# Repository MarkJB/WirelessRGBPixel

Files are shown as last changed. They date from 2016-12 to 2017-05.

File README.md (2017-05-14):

Copyright 2016 Mark Benson.

License: CC-NC-BY 4.0

No warranty implied or given. Use at your own risk.

Early testing code/electronics for proof of concept.

Wireless RGB Pixel is just that, a wireless (NRF24L01+) RGB led (WS2812b) controlled by an Atmel ATTiny85. One or more 'pixels' can be controlled by an Arduino with another NRF24L01+ module.

It is hoped that many of these 'pixels' can be manufactured and installed somewhere and controlled to create an interesting light show.

As of Dec 2016 PCB is at v1.2.

This version uses the original circuit design. No pin mux or serial debug is available.

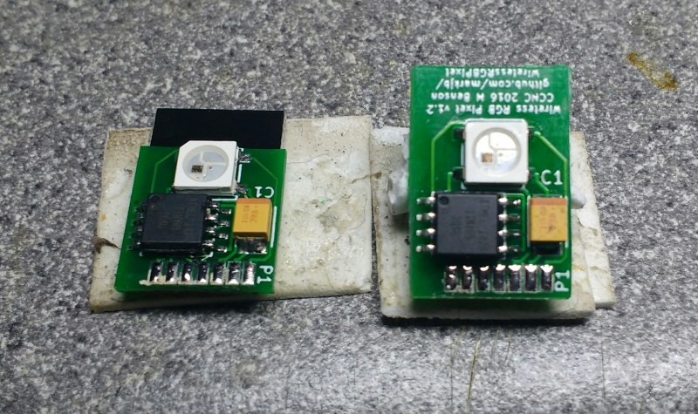
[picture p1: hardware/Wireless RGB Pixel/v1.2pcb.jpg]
v1.2 PCB


More details on the Make Bournemouth Wiki and forum.

https://www.makebournemouth.com/wiki2/index.php/RGB_Wireless_Pixel

https://www.makebournemouth.com/?page_id=39

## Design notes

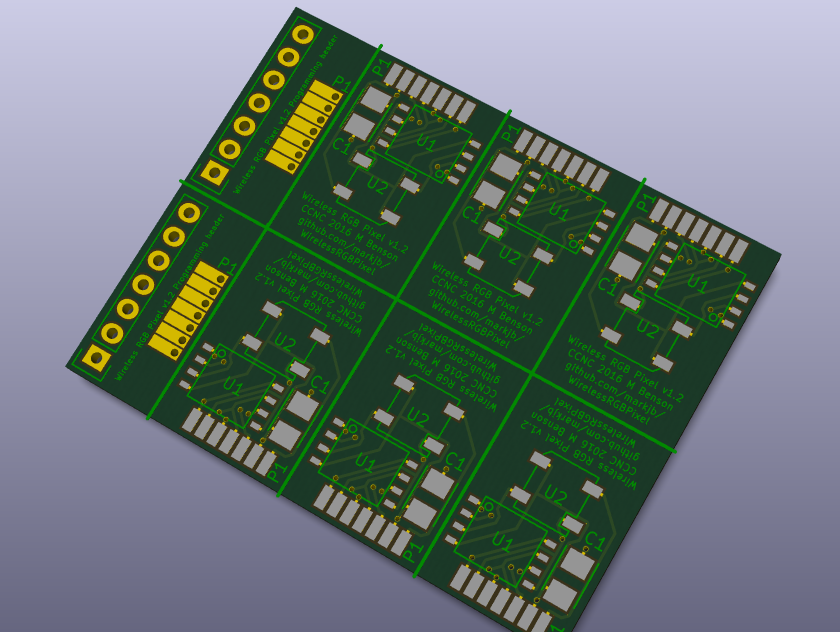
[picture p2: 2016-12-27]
hardware/Wireless RGB Pixel/tiny_pcb_1.2_panel3x2.png

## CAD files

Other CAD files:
hardware/Wireless RGB Pixel/pcb.stl

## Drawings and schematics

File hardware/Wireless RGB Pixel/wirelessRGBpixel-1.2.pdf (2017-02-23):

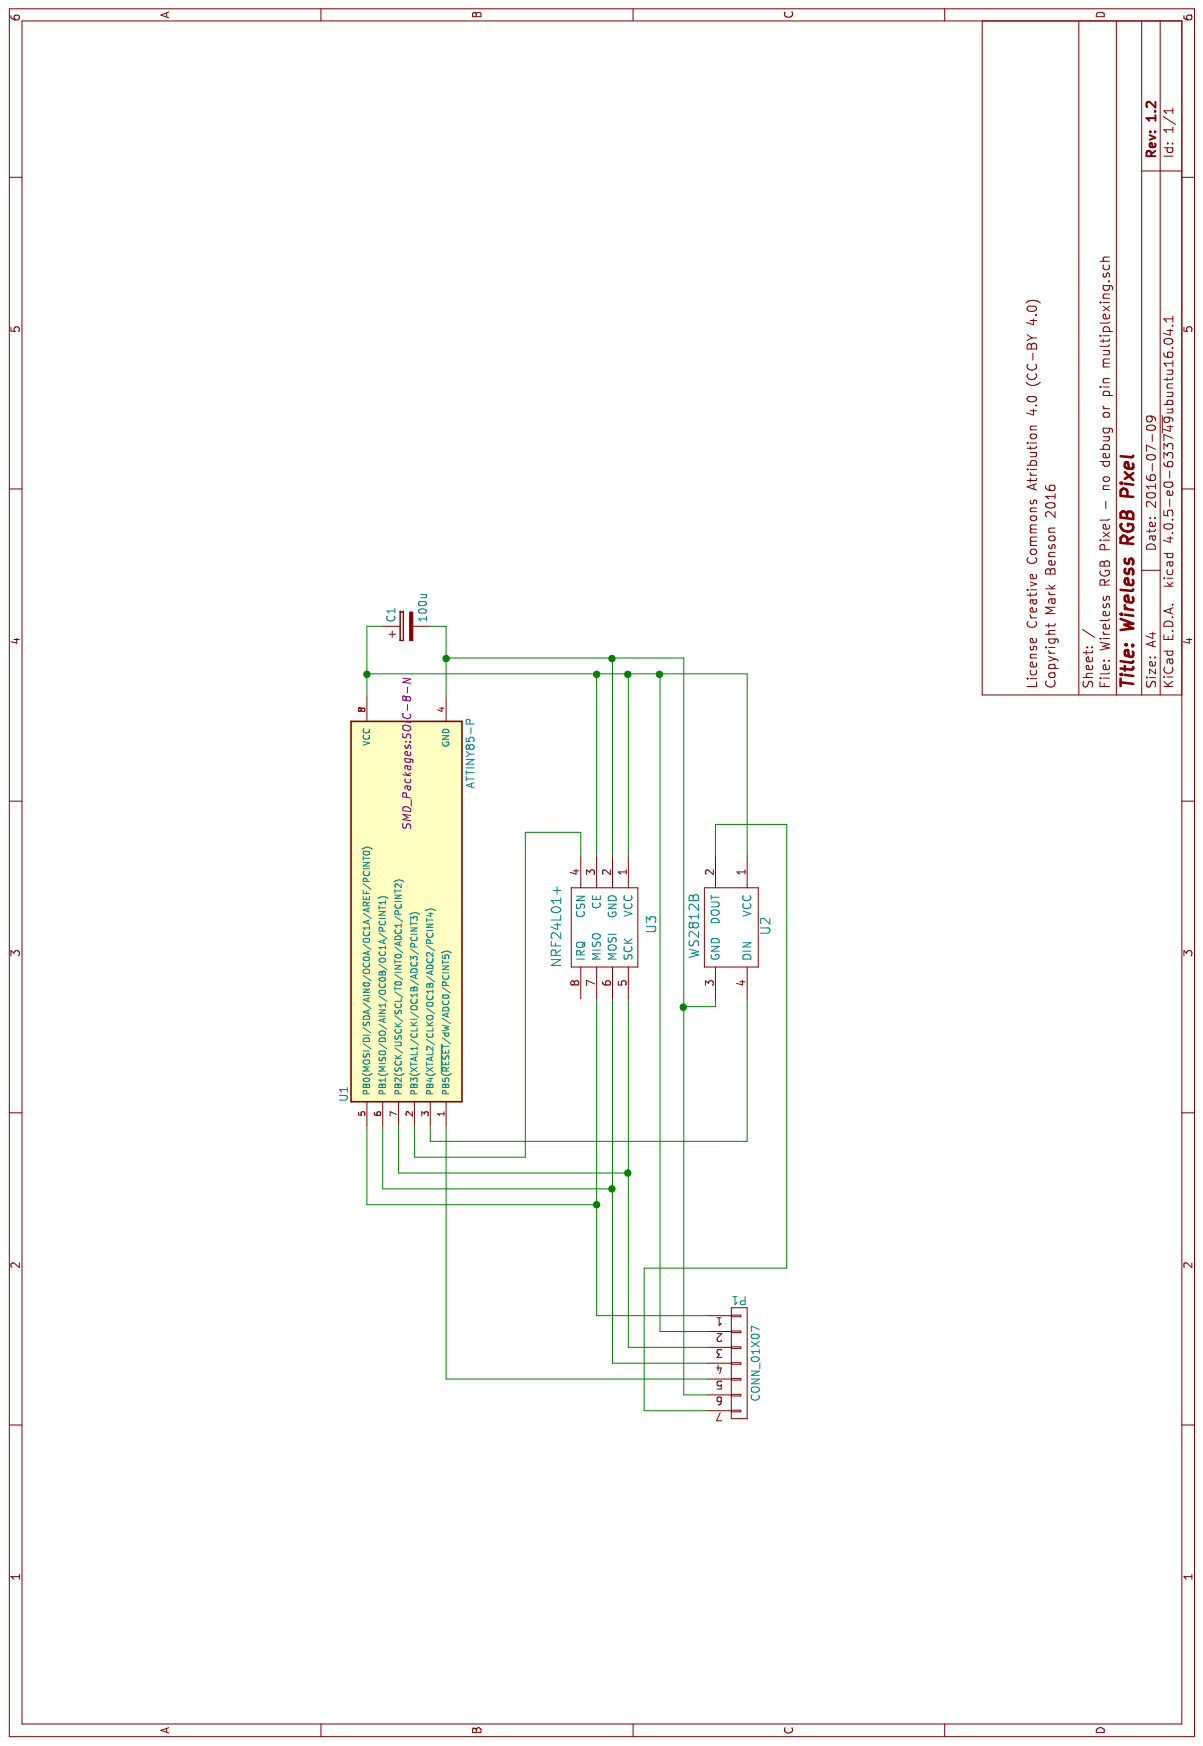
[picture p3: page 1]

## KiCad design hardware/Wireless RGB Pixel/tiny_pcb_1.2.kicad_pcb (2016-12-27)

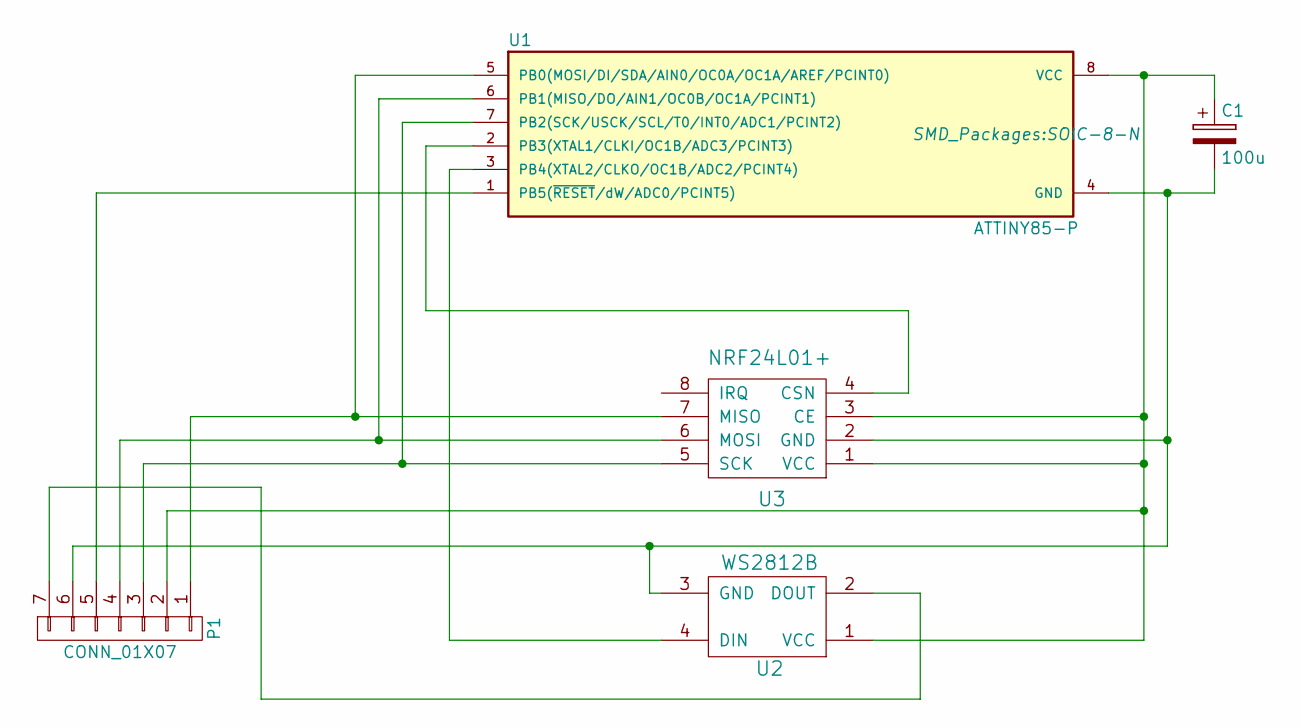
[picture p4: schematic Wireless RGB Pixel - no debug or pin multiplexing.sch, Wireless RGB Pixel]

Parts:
C1: 100u; TantalC_SizeB_EIA-3528_Reflow
P1: CONN_01X07; CONN7
U1: ATTINY85-P; SOIC-8-N
U2: WS2812B; WS2812B_SMT
U3: NRF24L01+; NRF24L01+_SMT

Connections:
unnamed: C1.1, P1.2, U1.8 (VCC), U2.1 (VCC), U3.1 (VCC), U3.3 (CE)
unnamed: C1.2, P1.6, U1.4 (GND), U2.3 (GND), U3.2 (GND)
unnamed: P1.1, U1.5 (PB0(MOSI/DI/SDA/AIN0/OC0A/OC1A/AREF/PCI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), U3.7 (MISO)
unnamed: P1.3, U1.7 (PB2(SCK/USCK/SCL/T0/INT0/ADC1/PCINT2)), U3.5 (SCK)
unnamed: P1.4, U1.6 (PB1(MISO/DO/AIN1/OC0B/OC1A/PCINT1)), U3.6 (MOSI)
unnamed: P1.5, U1.1 (PB5(~RESET~/dW/ADC0/PCINT5))
unnamed: P1.7, U2.2 (DOUT)
unnamed: U1.2 (PB3(XTAL1/CLKI/OC1B/ADC3/PCINT3)), U3.4 (CSN)
unnamed: U1.3 (PB4(XTAL2/CLKO/OC1B/ADC2/PCINT4)), U2.4 (DIN)

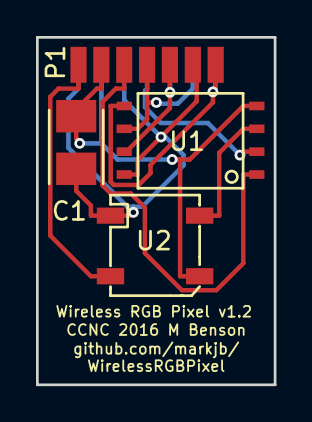
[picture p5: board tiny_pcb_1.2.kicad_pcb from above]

Board: 2 copper layers, 13.2 x 19.3 mm, 5 parts (1 on the bottom side), 9 nets.

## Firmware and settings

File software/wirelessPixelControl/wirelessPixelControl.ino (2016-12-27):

/*
* Getting Started example sketch for nRF24L01+ radios
* This is a very basic example of how to send data from one node to another
* Updated: Dec 2014 by TMRh20
*/

#include <SPI.h>
#include "RF24.h"

/****************** User Config ***************************/
/***      Set this radio as radio number 0 or 1         ***/
bool radioNumber = 0;

/* Hardware configuration: Set up nRF24L01 radio on SPI bus plus pins 7 & 8 */

// RF24 radio(CE,CSN)
// Arduino NANO NRF Adaptor board https://github.com/MarkJB/NRF24L01_Adaptors
RF24 radio(9,10);

/**********************************************************/

byte addresses[][6] = {"PIPE1","PIPE2"};

// Used to control whether this node is sending or receiving
bool role = 0;

int r,g,b;

void setup() {
  Serial.begin(115200);
  Serial.println("WirelessRGBPixel Control v1");
  Serial.println("Commands available:");
  Serial.println("Change colour: CR,G,B");
  Serial.println("Random colour: R");
  Serial.println("Turn off LEDs: O");
  Serial.println("Show this help info: H/?");
  Serial.println("Fade to black: Not implemented");
  Serial.println("Blend to colour: Not implemented");
  radio.begin();

  // Set the PA Level low to prevent power supply related issues since this is a
 // getting_started sketch, and the likelihood of close proximity of the devices. RF24_PA_MAX is default.
  radio.setPALevel(RF24_PA_MAX);
  
  // Open a writing and reading pipe on each radio, with opposite addresses
  if(radioNumber){
    radio.openWritingPipe(addresses[1]);
    radio.openReadingPipe(1,addresses[0]);
  }else{
    radio.openWritingPipe(addresses[0]);
    radio.openReadingPipe(1,addresses[1]);
  }
  
  // Start the radio listening for data
  radio.startListening();
}

void loop() 
{
  if ( Serial.available() )
  {
    char firstReceivedByte = toupper(Serial.read());
    
    switch(firstReceivedByte)
    {
      case 'C': //If the first char received is a 'C' that indicates a change colour CRGB command so get the rest of it and send it
      {
        Serial.println("Colour change command: Cn,n,n,a");
        byte sendRGBData[5] = {'C',0,0,0,0};  //Change colour command: C,R,G,B,a (defaults to off) where a is the pixel address 0-255 (0 is default and address all pixels)
        if (Serial.available() >= 2) 
        {
          for (int i=1; i<5; i++) 
          {
            sendRGBData[i] = Serial.parseInt(); 
            //sendRGBData[i] = Serial.read();
          }
        }

        for (int i=1; i<5; i++) 
        {
          Serial.print("Sending :");
          Serial.println(sendRGBData[i]);
        }
        
        radio.stopListening();
        // Send data over radio. Blocks until done
        if (!radio.write( &sendRGBData, sizeof(sendRGBData) ))
        {
          //Serial.println(F("failed"));
        }
        break; 
      }
      
      case 'R': //If the first char received is a 'R' that indicates a RANDOM change colour CRGB command so generate the rest of it and send it
      {
        Serial.println("Random Colour change command: R");
        byte sendRGBData[5] = {'C',0,0,0,0};  //Change colour command data (defaults to off)

        for (int i=1; i<4; i++) 
        {
          sendRGBData[i] = random(0,256); 
          //sendRGBData[i] = Serial.read();
        }

        for (int i=1; i<5; i++) 
        {
          Serial.print("Sending :");
          Serial.println(sendRGBData[i]);
        }

        radio.stopListening();
        // Send data over radio. Blocks until done
        if (!radio.write( &sendRGBData, sizeof(sendRGBData) ))
        {
          //Serial.println(F("failed"));
        }
        break; 
      }
      
      case 'O': //If the first char received is a 'O' turn off LEDs
      {
        Serial.println("Turn off LEDs command: O");
        byte sendRGBData[5] = {'C',0,0,0,0};  //Change colour command data (defaults to off)

        radio.stopListening();
        // Send data over radio. Blocks until done
        if (!radio.write( &sendRGBData, sizeof(sendRGBData) ))
        {
          //Serial.println(F("failed"));
        }
        break; 
      }
      
      case 'F': //Fade to black FN(F = fade command, N = amount to fade by)
      {
        Serial.println("Not yet implemented");
        break; 
      }
      
      case 'B': //Blend colour from current colour to BRGB
      {
        Serial.println("Not yet implemented"); 
        break; 
      }
      
      case '\r': //Control char, do nothing
      {
        //Serial.println("Control char"); 
        break; 
      }
      
      case '\n': //Control char, do nothing
      {
        //Serial.println("Control char"); 
        break; 
      }
      
      case 'H': //Show help
      case '?': //Show help
      {
        Serial.println("WirelessRGBPixel Control v1");
        Serial.println("Commands available:");
        Serial.println("Change colour: CR,G,B");
        Serial.println("Random colour: R");
        Serial.println("Turn off LEDs: O");
        Serial.println("Show this help info: H/?");
        Serial.println("Fade to black: Not implemented");
        Serial.println("Blend to colour: Not implemented");
        Serial.println("");
        break;
      }
     
      default: //Command not recoginsed, do nothing
      {
        Serial.println("Input not recognised");
        break;  
      }
    }
  }
} // Loop

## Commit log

2016-07-11 Initial commit
    PoC schematic and test software (largely based on the RF24 getting
    started examples. To be replaced with proper working code.)
    [Wireless RGB Pixel.kicad_pcb, Wireless RGB Pixel.sch, _saved_Wireless RGB Pixel.sch]
2016-08-29 Fix file extension and CE, CSN pin assignment
    [wirelessPixelControl.ino]
2016-12-27 v1.2, back to original design with no pin mux, no serial debug to simplify custom nrf lib
    [Wireless RGB Pixel - no debug or pin multiplexing.sch, Wireless RGB Pixel.kicad_pcb, Wireless RGB Pixel.sch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]
2016-12-27 Pic of assembled v1.2 pcb
2017-02-23 Updated schematic - no debug
    [Wireless RGB Pixel - no debug or pin multiplexing.sch, pcb.stl]

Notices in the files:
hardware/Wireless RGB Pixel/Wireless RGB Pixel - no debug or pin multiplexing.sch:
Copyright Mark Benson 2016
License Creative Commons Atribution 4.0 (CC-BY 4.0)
